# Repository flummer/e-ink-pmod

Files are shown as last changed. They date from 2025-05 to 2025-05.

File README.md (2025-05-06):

# E-Ink PMOD with SRAM

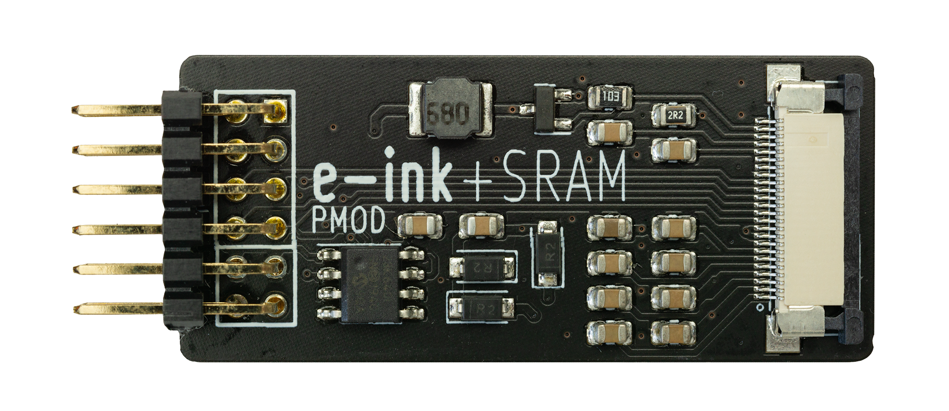
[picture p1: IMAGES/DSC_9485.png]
E-Ink PMOD with SRAM


## Features

- Simple PMOD form factor breakout board with the required components to drive an e-ink display from regular 3.3v electronics
- There is also an SRAM chip (23K640-I/SN) on board, eg. for use as a frame buffer

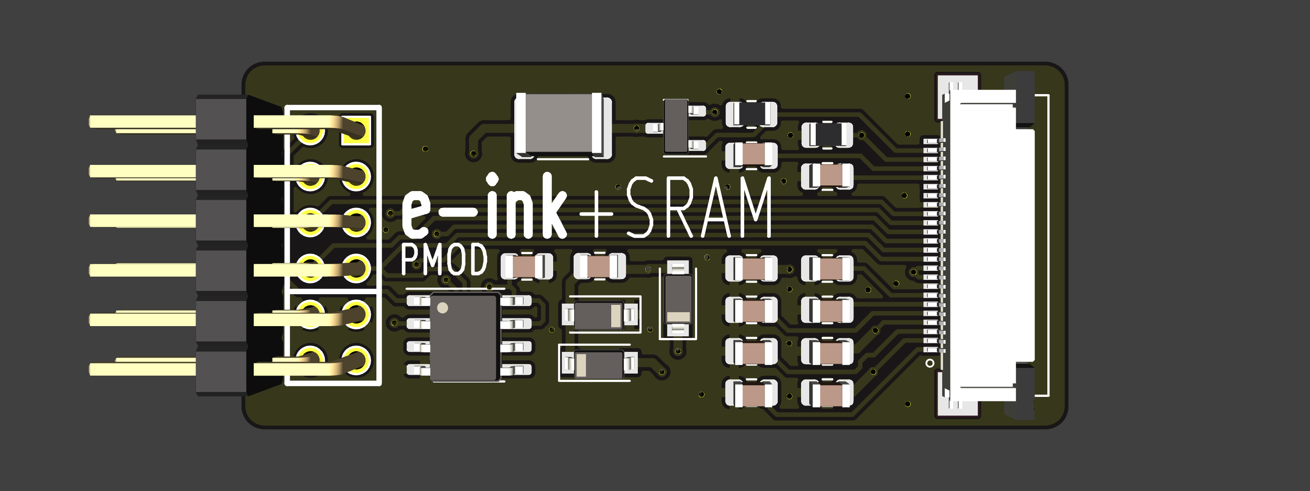
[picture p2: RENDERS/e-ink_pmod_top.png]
E-Ink PMOD with SRAM top

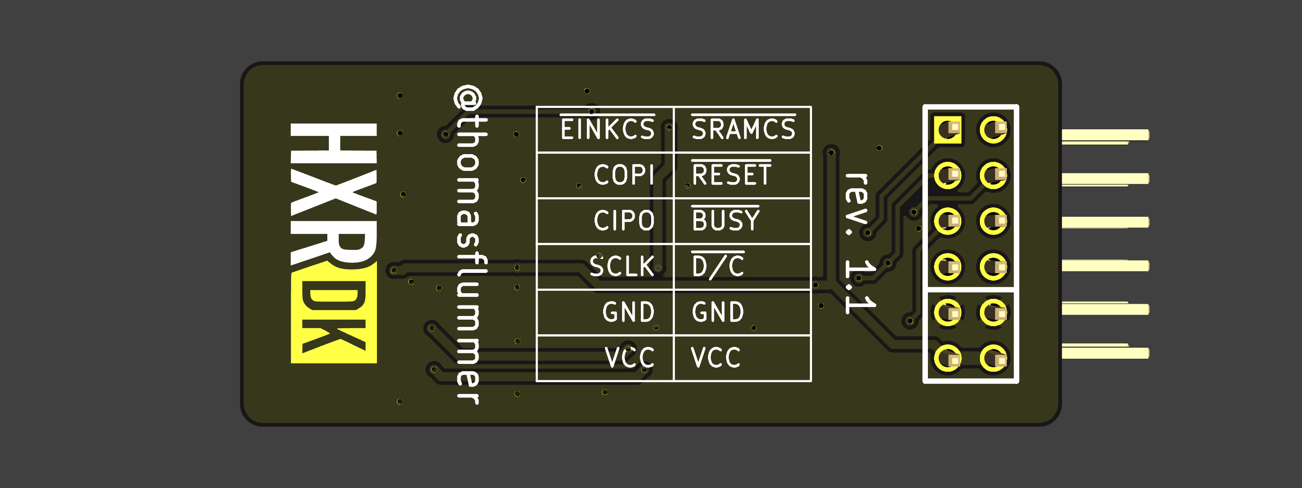
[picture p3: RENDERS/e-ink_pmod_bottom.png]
E-Ink PMOD with SRAM bottom

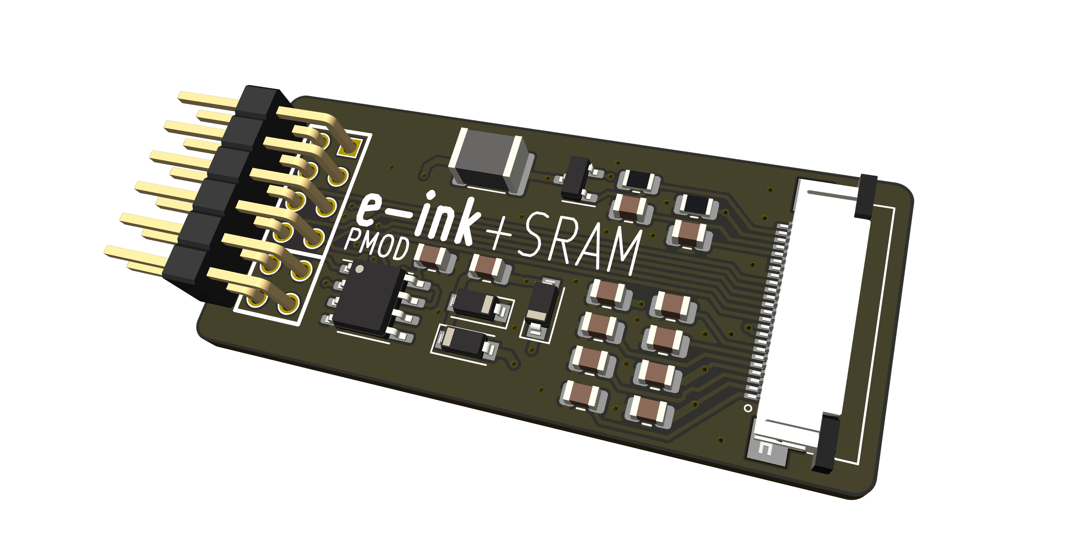
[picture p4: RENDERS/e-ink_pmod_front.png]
E-Ink PMOD with SRAM front


## Source files in KiCad v9

To open the project, you will need to install KiCad v9 or a nightly build. KiCad v8 or earlier won't open this design directly. Earlier commits will be saved in a previous version.

[Electronics schematics as a PDF file](https://github.com/flummer/e-ink-pmod/blob/main/schematic.pdf) is also included for reference.

[Design can also be viewed in the KiCanvas online viewer](https://kicanvas.org/?github=https%3A%2F%2Fgithub.com%2Fflummer%2Fe-ink-pmod)

## License

The hardware design in this repository is released under the following license:

* the "Creative Commons Attribution-ShareAlike 4.0 International License"
  (CC BY-SA 4.0) full text of this license is included in the LICENSE file
  and a copy can also be found at
  [http://creativecommons.org/licenses/by-sa/4.0/](http://creativecommons.org/licenses/by-sa/4.0/)

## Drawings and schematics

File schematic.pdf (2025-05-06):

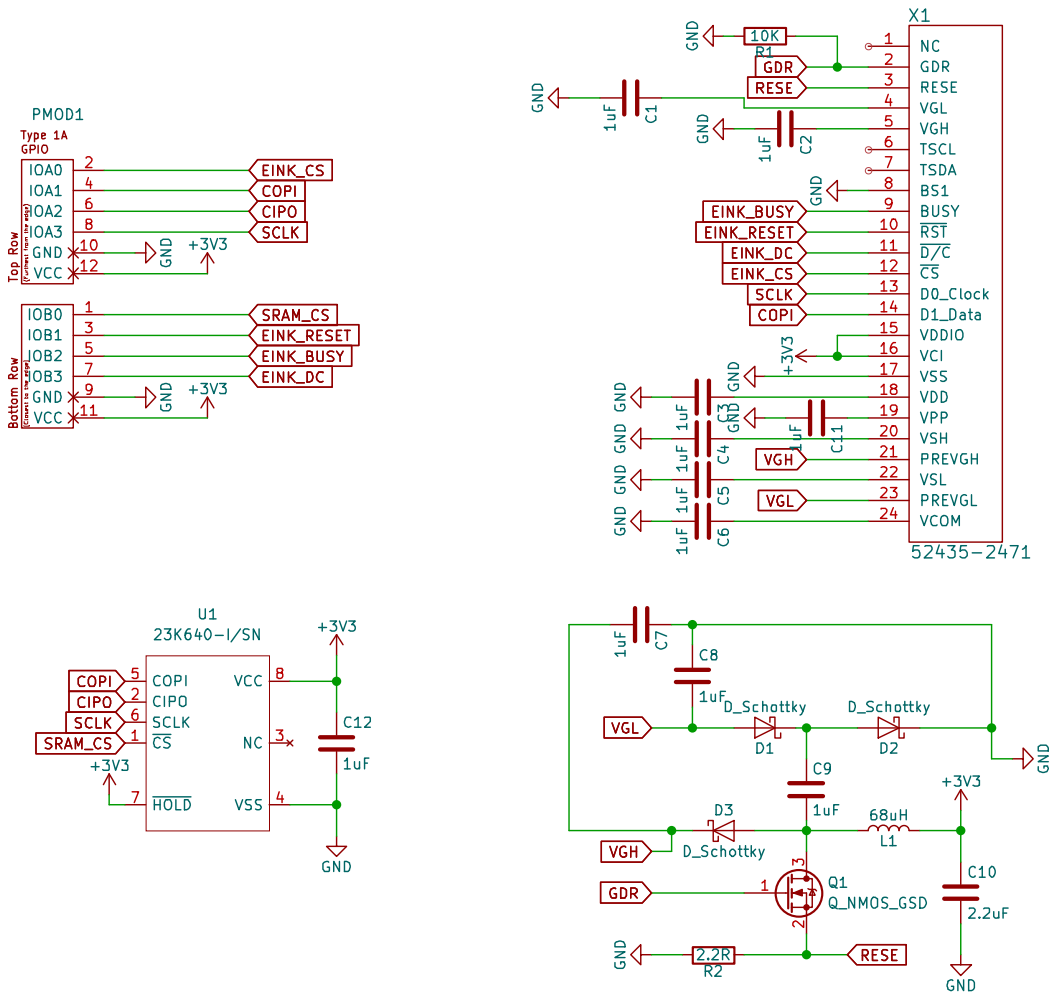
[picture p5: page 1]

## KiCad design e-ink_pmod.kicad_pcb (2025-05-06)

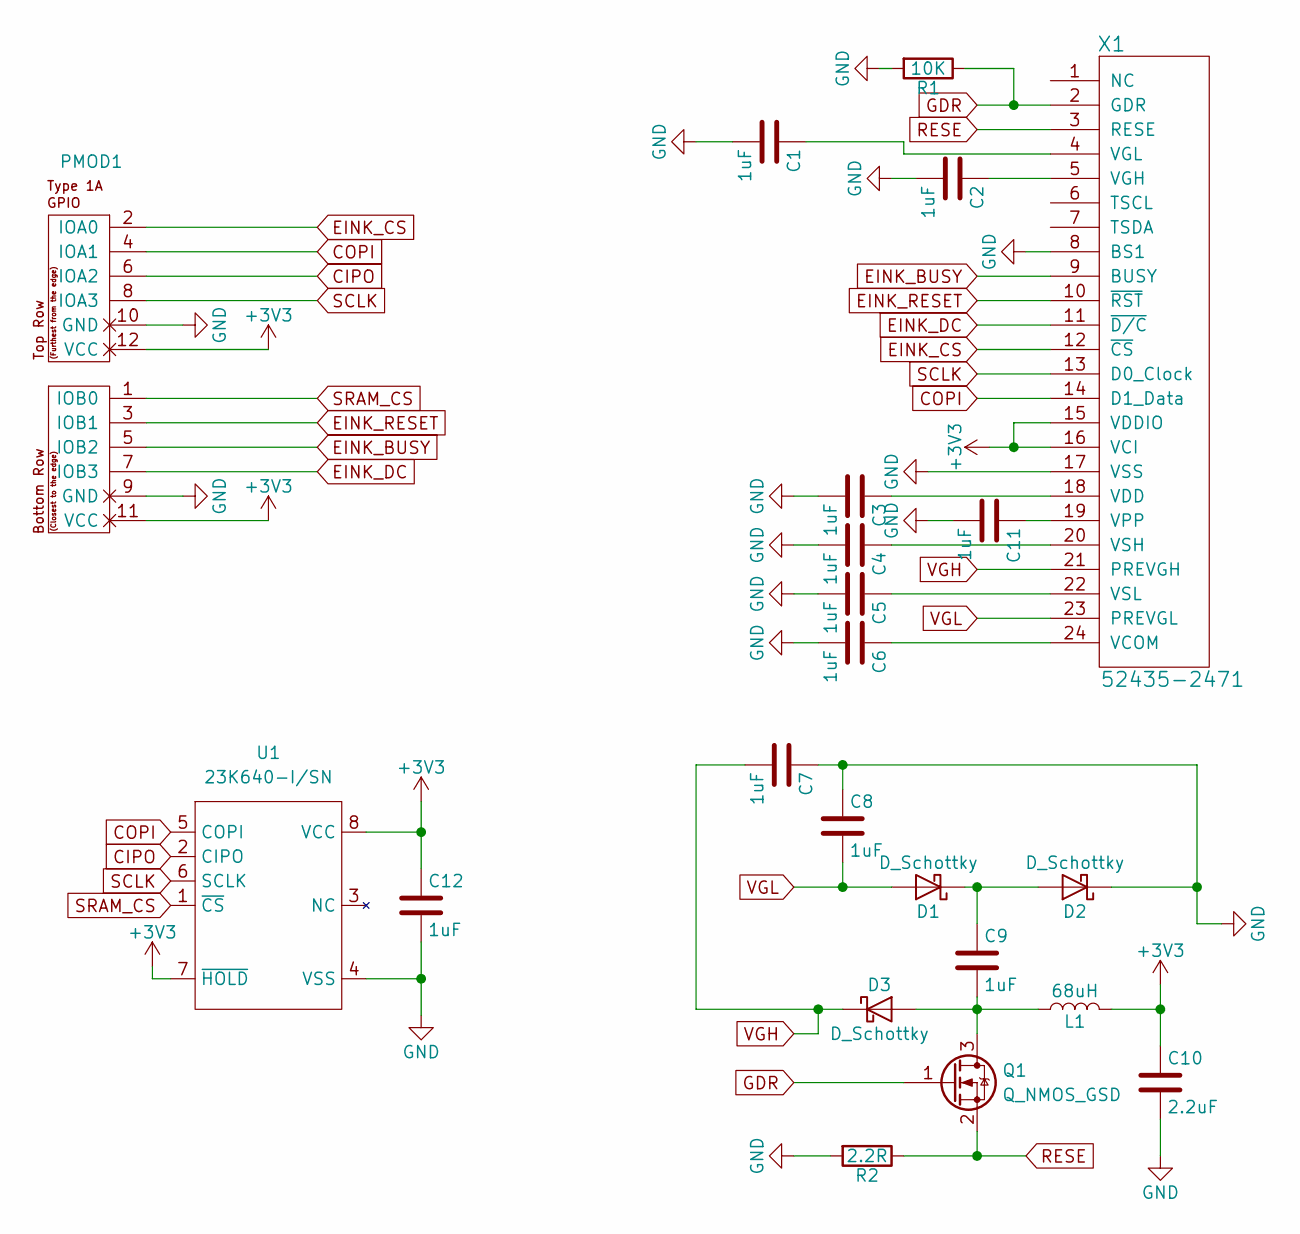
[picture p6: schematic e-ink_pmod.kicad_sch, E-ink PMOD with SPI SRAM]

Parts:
C1, C2, C3, C4, C5, C6, C7, C8, C9, C11, C12: 1uF; C_0805_2012Metric
C10: 2.2uF; C_0805_2012Metric
D1, D2, D3: D_Schottky; D_SOD-123
L1: 68uH; L_1812_4532Metric
PMOD1: QMOD-Device-x2-Type-1A-GPIO; pmod_pin_array_6x2
Q1: Q_NMOS_GSD; SOT-23
R1: 10K; R_0805_2012Metric
R2: 2.2R; R_0805_2012Metric
U1: 23K640-I/SN; SOIC-8_3.9x4.9mm_P1.27mm
X1: 52435-2471; MOLEX_52435-2471

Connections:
+3V3: C10.1, C12.1, L1.2, PMOD1.11 (VCC), PMOD1.12 (VCC), U1.7 (~HOLD), U1.8 (VCC), X1.15 (VDDIO), X1.16 (VCI); also elsewhere on the board
CIPO: PMOD1.6 (IOA2), U1.2 (CIPO); also elsewhere on the board
COPI: PMOD1.4 (IOA1), U1.5 (COPI), X1.14 (D1_Data); also elsewhere on the board
EINK_BUSY: PMOD1.5 (IOB2), X1.9 (BUSY); also elsewhere on the board
EINK_CS: PMOD1.2 (IOA0), X1.12 (~CS); also elsewhere on the board
EINK_DC: PMOD1.7 (IOB3), X1.11 (~D/C); also elsewhere on the board
EINK_RESET: PMOD1.3 (IOB1), X1.10 (~RST); also elsewhere on the board
GDR: Q1.1 (G), R1.1, X1.2 (GDR)
GND: C1.2, C2.2, C3.2, C4.2, C5.2, C6.2, C7.1, C8.1, C10.2, C11.2, C12.2, D2.1 (K), PMOD1.9 (GND), PMOD1.10 (GND), R1.2, R2.2, U1.4 (VSS), X1.8 (BS1), X1.17 (VSS); also elsewhere on the board
unnamed: C1.1, X1.4 (VGL)
unnamed: C2.1, X1.5 (VGH)
unnamed: C3.1, X1.18 (VDD)
unnamed: C4.1, X1.20 (VSH)
unnamed: C5.1, X1.22 (VSL)
unnamed: C6.1, X1.24 (VCOM)
unnamed: C9.1, D1.1 (K), D2.2 (A)
unnamed: C9.2, D3.2 (A), L1.1, Q1.3 (D)
unnamed: C11.1, X1.19 (VPP)
RESE: Q1.2 (S), R2.1, X1.3 (RESE)
SCLK: PMOD1.8 (IOA3), U1.6 (SCLK), X1.13 (D0_Clock); also elsewhere on the board
SRAM_CS: PMOD1.1 (IOB0), U1.1 (~CS); also elsewhere on the board
VGH: C7.2, D3.1 (K), X1.21 (PREVGH)
VGL: C8.2, D1.2 (A), X1.23 (PREVGL)

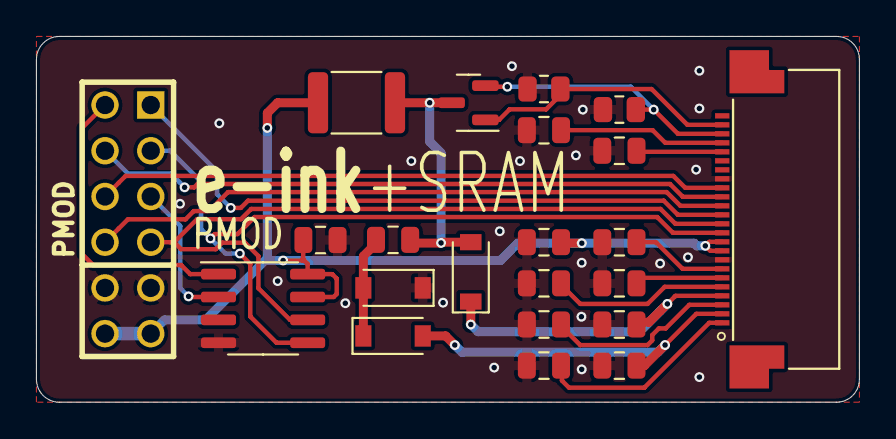
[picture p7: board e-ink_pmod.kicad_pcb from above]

Board: 2 copper layers, 45.7 x 20.3 mm, 22 parts (0 on the bottom side), 23 nets.

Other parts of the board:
PMOD: QMOD-Device-x2-Type-1A-GPIO; pmod_pin_array_6x2

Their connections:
+3V3: PMOD.11 (VCC), PMOD.12 (VCC); also elsewhere on the board
CIPO: PMOD.6 (IOA2); also elsewhere on the board
COPI: PMOD.4 (IOA1); also elsewhere on the board
EINK_BUSY: PMOD.5 (IOB2); also elsewhere on the board
EINK_CS: PMOD.2 (IOA0); also elsewhere on the board
EINK_DC: PMOD.7 (IOB3); also elsewhere on the board
EINK_RESET: PMOD.3 (IOB1); also elsewhere on the board
GND: PMOD.9 (GND), PMOD.10 (GND); also elsewhere on the board
SCLK: PMOD.8 (IOA3); also elsewhere on the board
SRAM_CS: PMOD.1 (IOB0); also elsewhere on the board

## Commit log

2021-01-03 Added SPI SRAM for framebuffer
    Also updated to new KiCad version 6 file formats
    [e-ink_pmod-B_Cu.gbl, e-ink_pmod-B_Mask.gbs, e-ink_pmod-B_Paste.gbp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]
2021-01-07 Fixed dimension and changed display unit
    [e-ink_pmod.kicad_pcb]
2025-05-06 Updated documentation
    Also updated KiCad version for better compatibility with KiCanvas
    [e-ink_pmod.kicad_pcb, e-ink_pmod.kicad_sch]
